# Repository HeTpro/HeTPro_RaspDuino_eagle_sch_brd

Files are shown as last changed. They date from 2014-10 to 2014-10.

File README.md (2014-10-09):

HeTPro_RaspDuino_eagle_sch_brd
==============================

Esquematico y Board del RaspDuino
HeTPro - Herramientas Tecnologicas Profesionales
Guadalajara, Jalisco. 

Diseño creado bajo la licencia CC Creative Commons

Attribution-ShareAlike 4.0 International (CC BY-SA 4.0) 
http://creativecommons.org/licenses/by-sa/4.0/

www.hetpro.com.mx
contacto@hetpro.com.mx

El diseño creado bajo esta licencia es libre de:

Compartir - Compartir y distribuir el material en culquier medio o formato.
Modificar - Adaptar, transformar y reconstruir el material.

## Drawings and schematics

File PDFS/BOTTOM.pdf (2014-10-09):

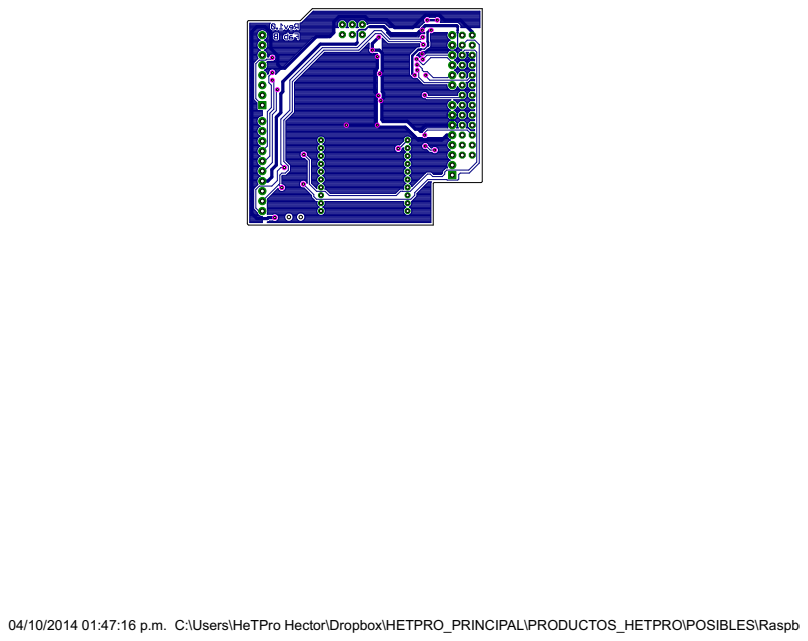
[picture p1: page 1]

04/10/2014 01:47:16 p.m. C:\Users\HeTPro Hector\Dropbox\HETPRO_PRINCIPAL\PRODUCTOS_HETPRO\POSIBLES\Raspberry PI shield\Revision 5\pi_shield_R4.brd

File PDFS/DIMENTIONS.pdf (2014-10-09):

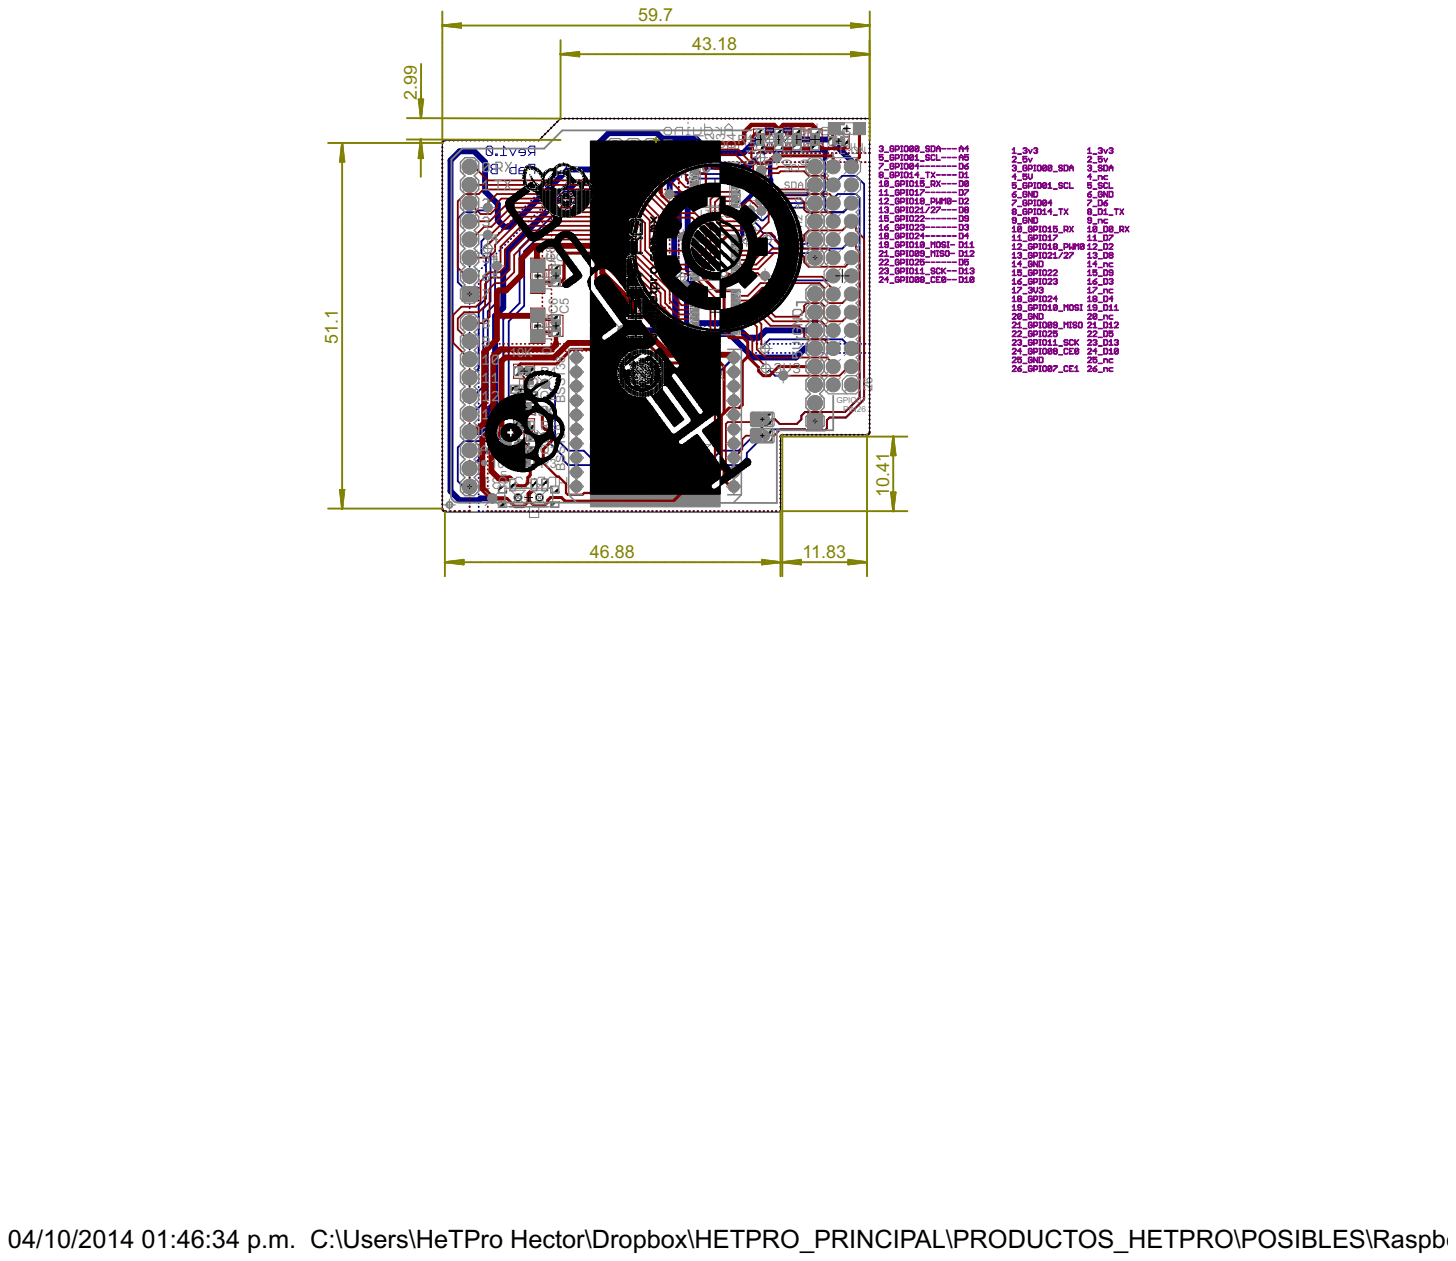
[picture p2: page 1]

04/10/2014 01:46:34 p.m. C:\Users\HeTPro Hector\Dropbox\HETPRO_PRINCIPAL\PRODUCTOS_HETPRO\POSIBLES\Raspberry PI shield\Revision 5\pi_shield_R4.brd

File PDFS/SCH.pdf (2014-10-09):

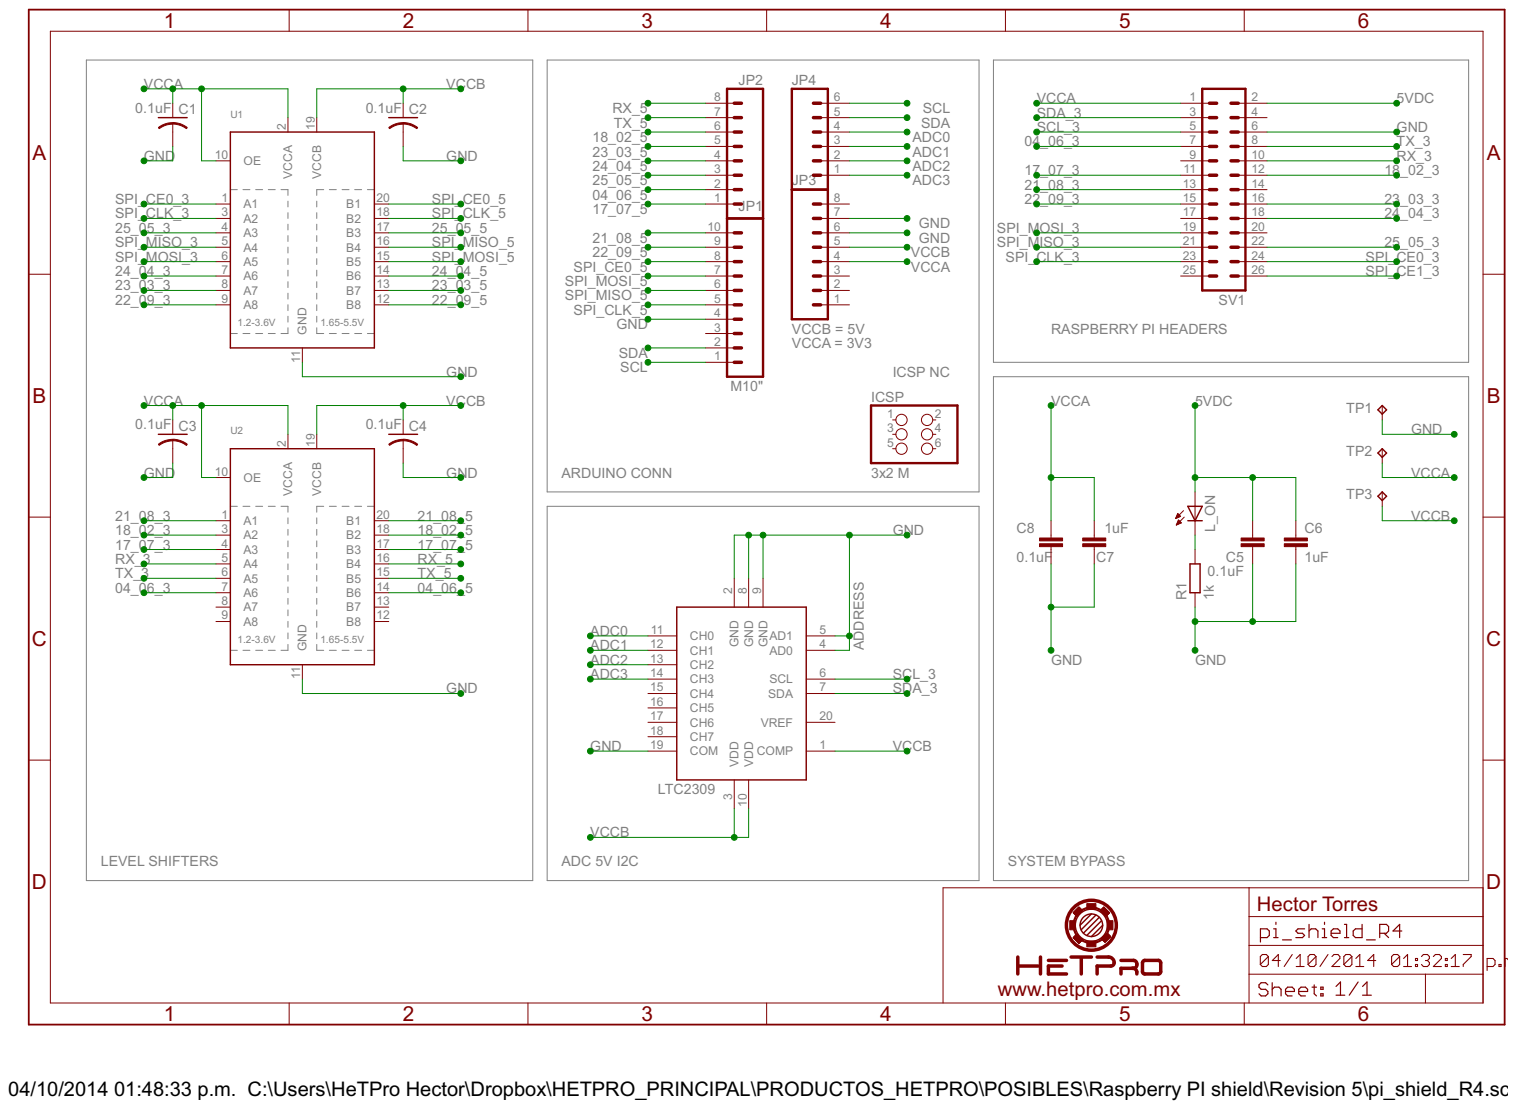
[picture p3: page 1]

www.hetpro.com.mx

04/10/2014 01:48:33 p.m. C:\Users\HeTPro Hector\Dropbox\HETPRO_PRINCIPAL\PRODUCTOS_HETPRO\POSIBLES\Raspberry PI shield\Revision 5\pi_shield_R4.sch (Sheet: 1/1)

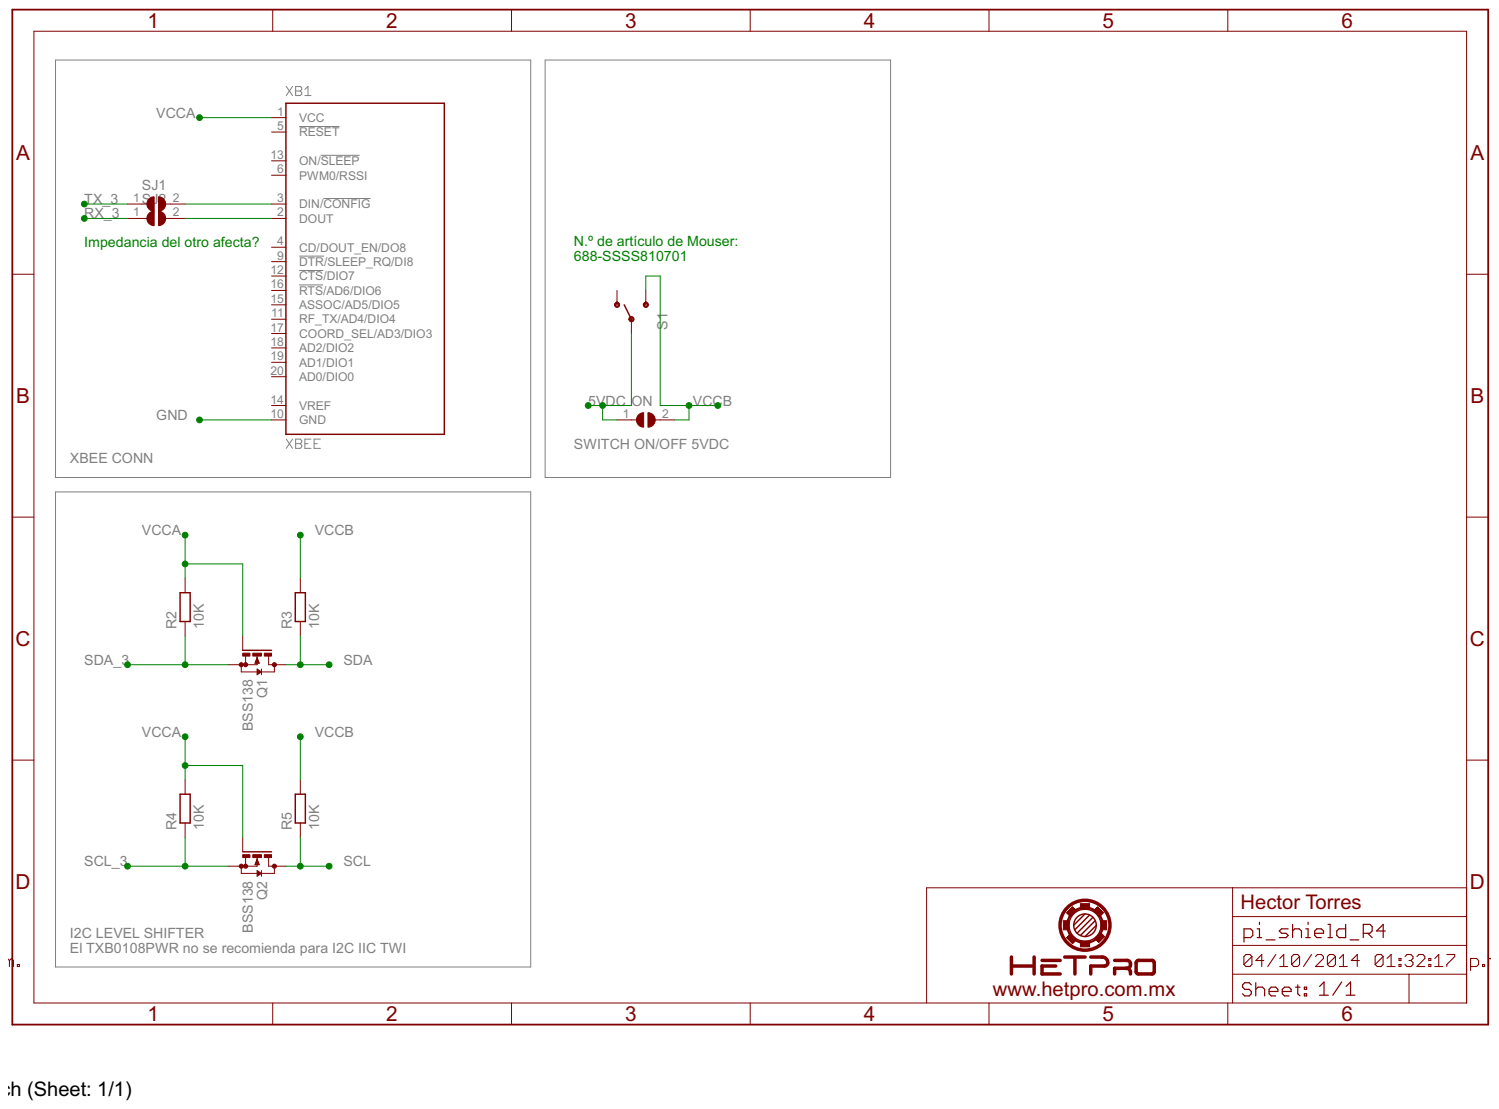
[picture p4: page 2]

I2C LEVEL SHIFTER
El TXB0108PWR no se recomienda para I2C IIC TWI

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

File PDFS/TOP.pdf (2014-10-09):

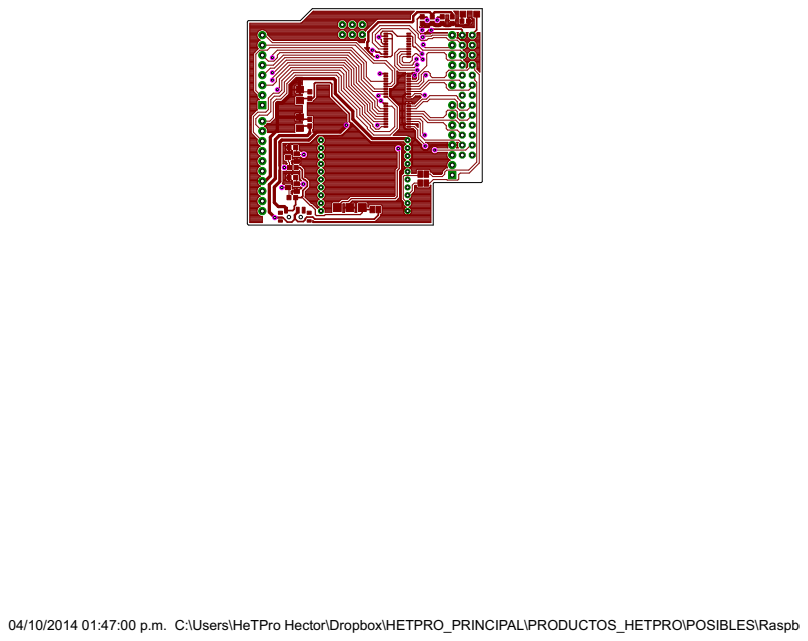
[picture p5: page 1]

04/10/2014 01:47:00 p.m. C:\Users\HeTPro Hector\Dropbox\HETPRO_PRINCIPAL\PRODUCTOS_HETPRO\POSIBLES\Raspberry PI shield\Revision 5\pi_shield_R4.brd

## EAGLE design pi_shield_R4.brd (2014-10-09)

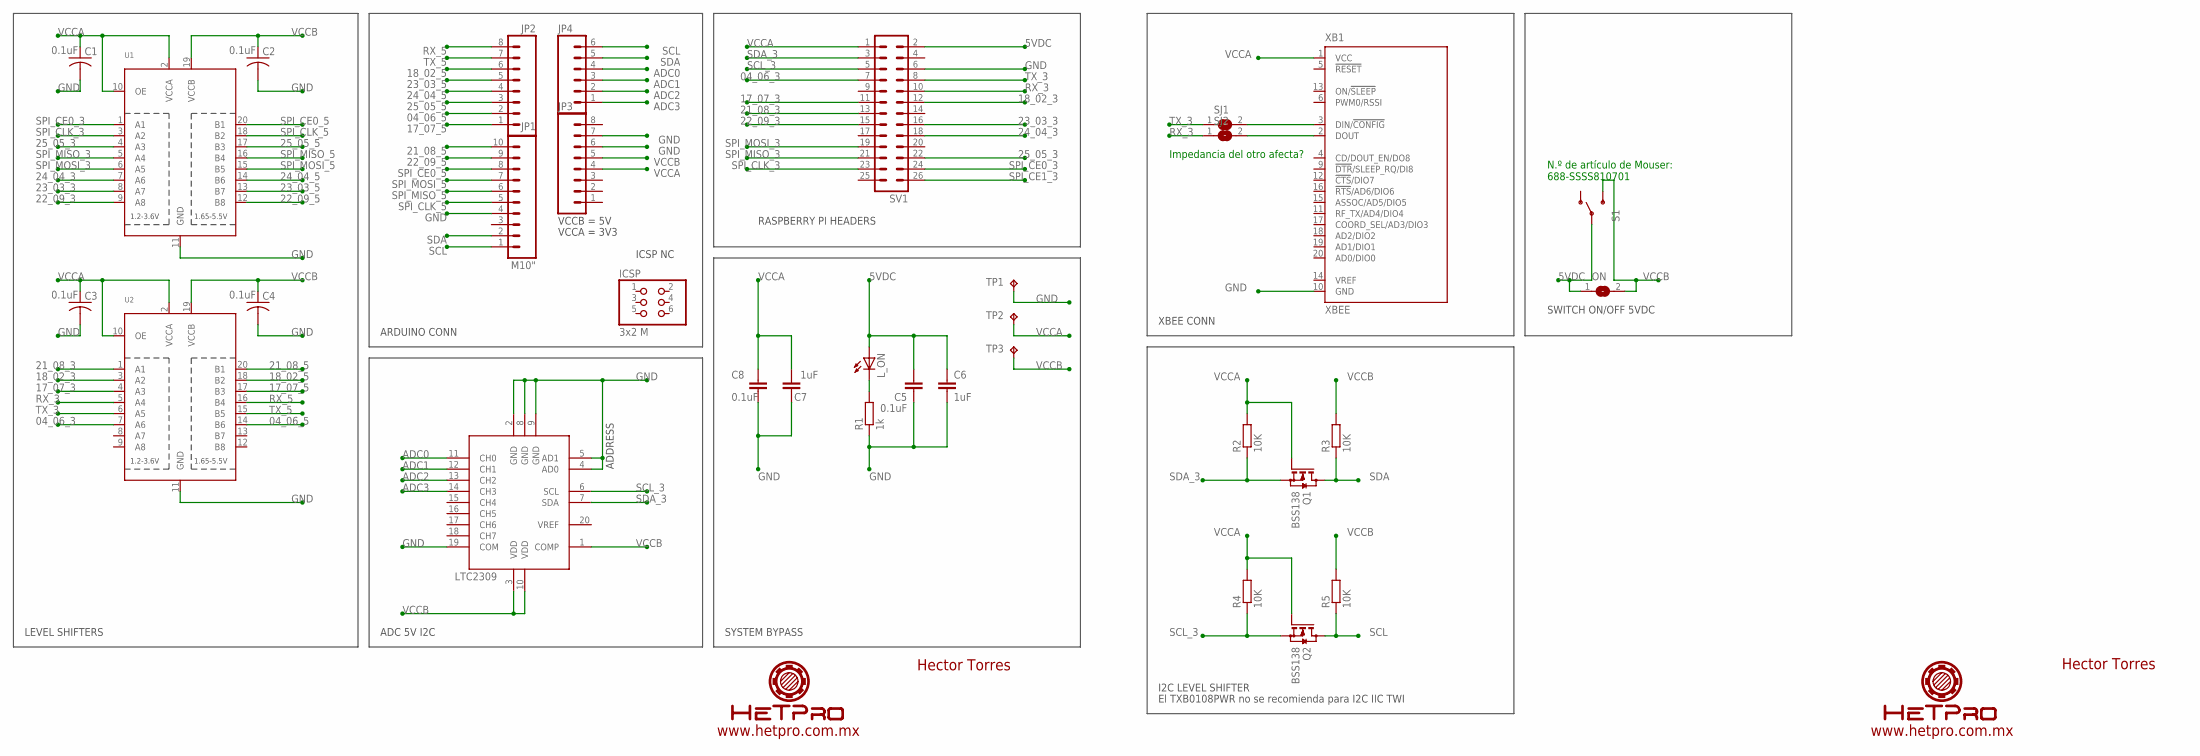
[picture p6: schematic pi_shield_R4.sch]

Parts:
C1, C2, C3, C4, C5: 0.1uF; C0603
C6: 1uF; C1206
C7: 1uF; C0603
C8: 0.1uF; C1206
ICSP: 3x2 M; 2X03
JP1: M10"; 1X10
JP2, JP3: M081X08; 1X08
JP4: M06SIP; 1X06
L_ON: LEDCHIPLED_1206; CHIPLED_1206
ON: SJ
Q1, Q2: BSS138; SOT23
R1: 1k; R0603
R2, R3, R4, R5: 10K; R0603
S1: SWITCH-SPST-SMD-A
SJ1, SJ2: SJ
SV1: MA13-2
TP1, TP2, TP3: TPTP20SQ; TP20SQ
U1, U2: TXB0108PWR; TSSOP20
U$4: LTC2309; TSSOP20
XB1: XBEE

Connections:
04_06_3: SV1.7, U2.7 (A6)
04_06_5: JP2.2, U2.14 (B6)
5VDC: C5.2, C6.1, L_ON.A, ON.1, S1.2, SV1.2
17_07_3: SV1.11, U2.4 (A3)
17_07_5: JP2.1, U2.17 (B3)
18_02_3: SV1.12, U2.3 (A2)
18_02_5: JP2.6, U2.18 (B2)
21_08_3: SV1.13, U2.1 (A1)
21_08_5: JP1.10, U2.20 (B1)
22_09_3: SV1.15, U1.9 (A8)
22_09_5: JP1.9, U1.12 (B8)
23_03_3: SV1.16, U1.8 (A7)
23_03_5: JP2.5, U1.13 (B7)
24_04_3: SV1.18, U1.7 (A6)
24_04_5: JP2.4, U1.14 (B6)
25_05_3: SV1.22, U1.4 (A3)
25_05_5: JP2.3, U1.17 (B3)
ADC0: JP4.4, U$4.11 (CH0)
ADC1: JP4.3, U$4.12 (CH1)
ADC2: JP4.2, U$4.13 (CH2)
ADC3: JP4.1, U$4.14 (CH3)
GND: C1.2, C2.2, C3.2, C4.2, C5.1, C6.2, C7.1, C8.2, JP1.4, JP3.6, JP3.7, R1.1, SV1.6, TP1.TP, U1.11 (GND), U2.11 (GND), U$4.2 (GND), U$4.4 (AD0), U$4.5 (AD1), U$4.8 (GND), U$4.9 (GND), U$4.19 (COM), XB1.10 (GND)
unnamed: SJ1.2, XB1.3 (DIN/!CONFIG)
unnamed: SJ2.2, XB1.2 (DOUT)
unnamed: L_ON.C, R1.2
RX_3: SJ2.1, SV1.10, U2.5 (A4)
RX_5: JP2.8, U2.16 (B4)
SCL: JP1.1, JP4.6, Q2.3 (D), R5.1
SCL_3: Q2.2 (S), R4.1, SV1.5, U$4.6 (SCL)
SDA: JP1.2, JP4.5, Q1.3 (D), R3.1
SDA_3: Q1.2 (S), R2.1, SV1.3, U$4.7 (SDA)
SPI_CE0_3: SV1.24, U1.1 (A1)
SPI_CE0_5: JP1.8, U1.20 (B1)
SPI_CE1_3: SV1.26
SPI_CLK_3: SV1.23, U1.3 (A2)
SPI_CLK_5: JP1.5, U1.18 (B2)
SPI_MISO_3: SV1.21, U1.5 (A4)
SPI_MISO_5: JP1.6, U1.16 (B4)
SPI_MOSI_3: SV1.19, U1.6 (A5)
SPI_MOSI_5: JP1.7, U1.15 (B5)
TX_3: SJ1.1, SV1.8, U2.6 (A5)
TX_5: JP2.7, U2.15 (B5)
VCCA: C1.1, C3.1, C7.2, C8.1, JP3.4, Q1.1 (G), Q2.1 (G), R2.2, R4.2, SV1.1, TP2.TP, U1.2 (VCCA), U1.10 (OE), U2.2 (VCCA), U2.10 (OE), XB1.1 (VCC)
VCCB: C2.1, C4.1, JP3.5, ON.2, R3.2, R5.2, S1.3 (S), TP3.TP, U1.19 (VCCB), U2.19 (VCCB), U$4.1 (COMP), U$4.3 (VDD), U$4.10 (VDD)

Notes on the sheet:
Impedancia del otro afecta?
N.º de artículo de Mouser: 688-SSSS810701
ARDUINO CONN
VCCB = 5V
VCCA = 3V3
ICSP NC
LEVEL SHIFTERS
XBEE CONN
I2C LEVEL SHIFTER
El TXB0108PWR no se recomienda para I2C IIC TWI
ADDRESS
SWITCH ON/OFF 5VDC
RASPBERRY PI HEADERS
SYSTEM BYPASS
ADC 5V I2C
www.hetpro.com.mx
Hector Torres

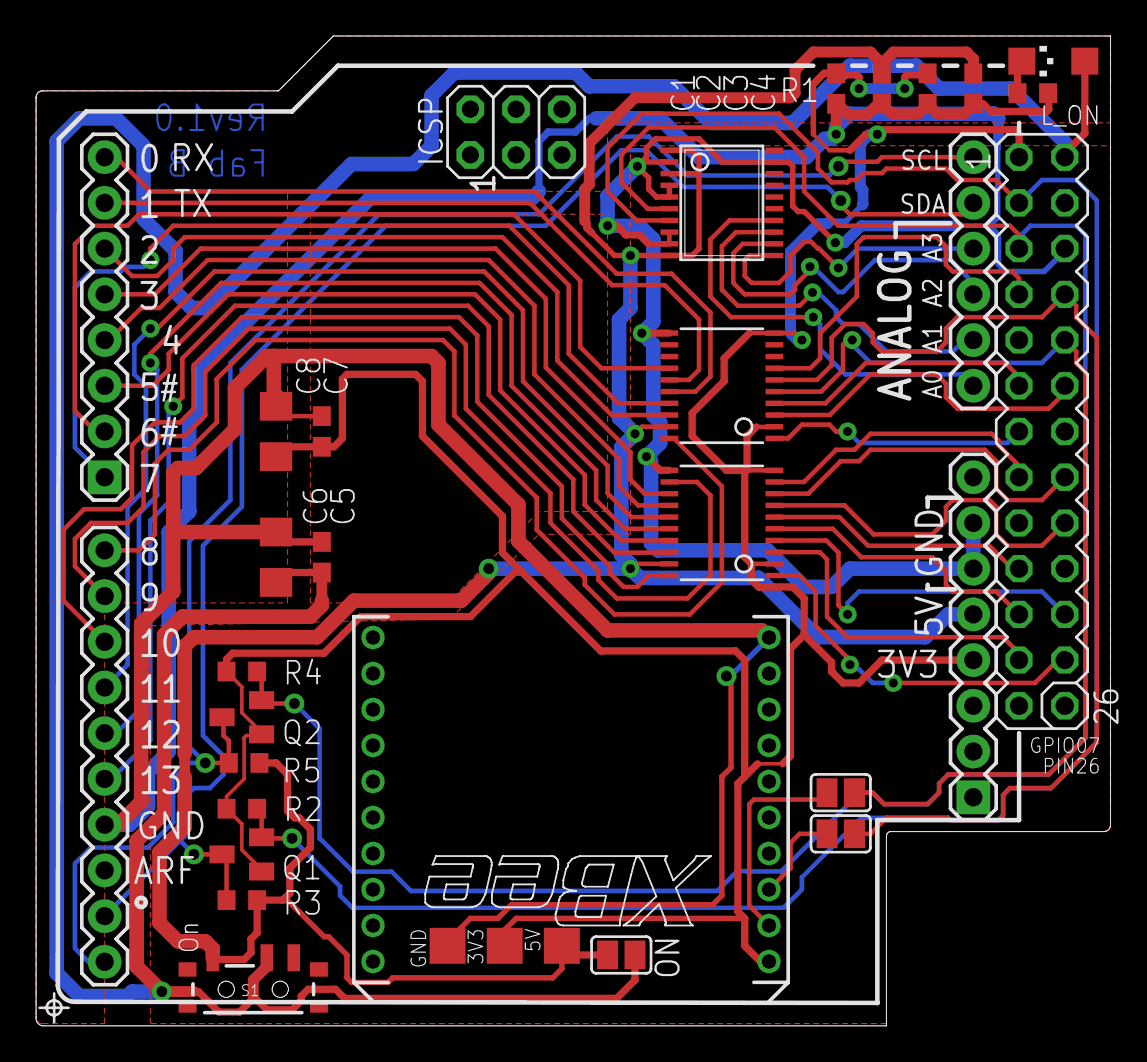
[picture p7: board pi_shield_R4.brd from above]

Board: 2 copper layers, 59.7 x 55.0 mm, 33 parts (0 on the bottom side), 43 nets.

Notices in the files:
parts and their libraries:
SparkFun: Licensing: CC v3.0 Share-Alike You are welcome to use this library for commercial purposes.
